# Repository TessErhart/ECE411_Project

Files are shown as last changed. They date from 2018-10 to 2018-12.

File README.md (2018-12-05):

# ECE411 Project 2018
Group 2
Team members: Tess Erhart, Jennifer Lara, Brandon Barber, and Martin Rodriguez

# Word Clock

Concept: Rather than displaying the time like a traditional clock, this clock uses LEDs to light words on a panel, “spelling out” the time.

Inspiration:<br/>
<https://www.amazon.com/LED-Word-Clock-Displays-Powered/dp/B00JPNWR3G><br/>
<https://www.instructables.com/id/Wordclock/>

/datasheets: Contains all relevant datasheets<br/>
/docs: Contains all relevant documents, schematics, layouts, testing plans, etc.<br/>
/rtc_ds3231: Contains all code<br/>
/schematics: Contains all schematics and layouts<br/>

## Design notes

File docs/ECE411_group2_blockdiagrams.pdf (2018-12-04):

Group 2:
Teresa Erhart
Jennifer Lara
Charles Barber
Martin Rodriguez

ECE 411

29 November 2018

Level 0 block diagram for Word Clock module

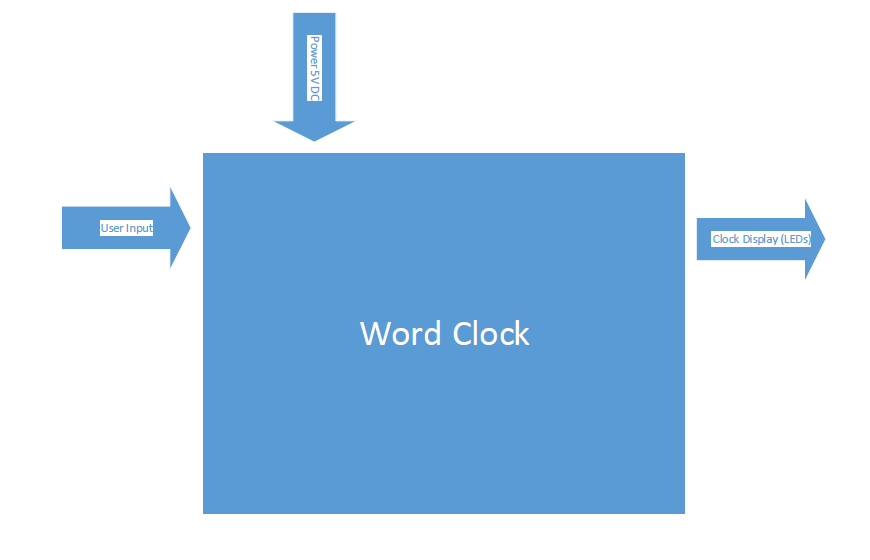
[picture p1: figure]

Module | Word Clock
Inputs | Power: 5V DC User control
Outputs | Display: LEDs
Functionality | User sets clock via pushbutton input. Word clock outputs LED voltages, which have been demultiplexed. LEDs are displayed through laser-cut acrylic so that words are shown representing the time.

Level 1 block diagram for Word Clock module

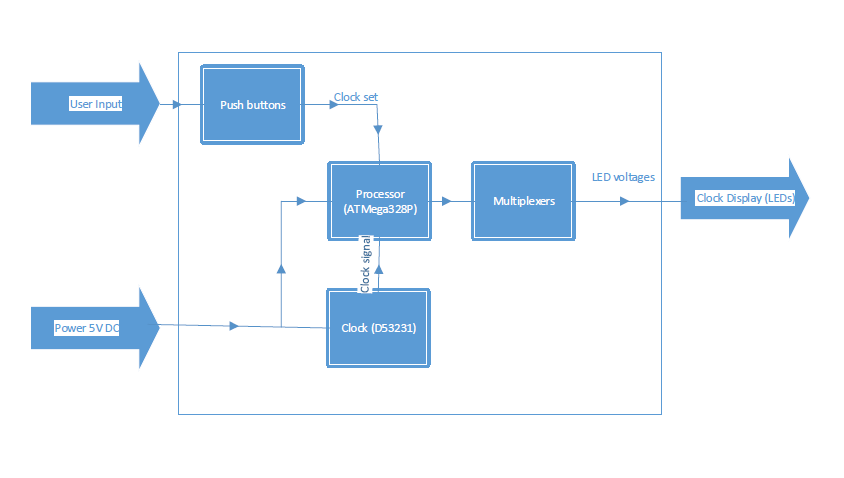
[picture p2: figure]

Module | Word Clock
Inputs | Power: 5V DC User control: two push buttons, A and B
Outputs | Display: LEDs (demultiplexed LED voltages)
Functionality | Push buttons are used to set clock. Clock provides signal to processor. Processor produces multiplexed signal, which must be demultiplexed to drive the LED display. Each LED represents a word, which is displayed through laser-cut acrylic to produce the word visually.

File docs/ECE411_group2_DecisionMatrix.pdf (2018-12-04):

Teresa Erhart
Charles Barber
Martin Rodriguez
Jennifer Lara

### ECE-411 Decision Matrix, Group Two

Introduction:

For our ECE-411 project we used a variety of decisions matrices to narrow down and conclude certain components of our project. These decisions lead to successful project development techniques within our group. Below is a list of our four entries:

Decision Matrix One: Deciding on our Practicum Project Based on Difficulty:

For the first decision matrix we implemented, it involved choosing our practicum project. We arranged the projects into a table and broke them down based off how difficult we though they would be on a scale of one to five. One being the easiest and five being the hardest. Below is a look at what this table was composed of:

Project Ideas: | Difficulty (1 to 5):
Guitar Modulator | 5
Collision Sensor | 4
Multidirectional LED Audio Sensor | 4
Word Clock | 2

Now these values that we listed were just a combination of us as a group talking through the time that each one would take to build, the construction, and overall difficulty. These values were also the average number that all of us individually came up with based off our thoughts of the project.

Decision Matrix Two: Layout and Designs Further Breakdown

Deciding what we wanted the board to look like, what components, the sizing, etc. all were up for consideration. Budget is also a big factor, so we needed to make a matrix of what we wanted vs. was this realistic for the time and money we have, also the factor of is this consumer friendly.

Each category graded on a 1 to 10 scale: | Guitar Modulator | Collision Sensor | Multidirectional LED Audio Sensor | Word Clock
Cost: | 7 | 5 | 8 | 4
Time: | 9 | 6 | 8 | 4
Size: | 4 | 3 | 7 | 4
Consumer Consumption: (in this case lower is better) | 3 | 5 | 7 | 2
Total: | 23 | 19 | 30 | 14

As we can see from the matrix above, the lower value is better and the project we would decide on.

Teresa Erhart
Charles Barber
Martin Rodriguez
Jennifer Lara
Decision Matrix Three: Word Clock, Breaking up the work

The next important factor that we though of was creating a decision matrix of our strengths. Group organization is key when creating a project. So, we built a matrix of who has strengths in certain areas and can contribute the most in that area or take lead.

Group Member: | Soldering: | Eagle: PCB Layout | Eagle: Schematic | Coding: | GitHub: | Documentation:
Teresa | x | x | x | | | x
Martin | x | | | | x | x
Jennifer | x | | x | x | | x
Charles | x | x | | | | x

Again, these areas don’t reflect what a person solely focused on, just more so what their main strengths are and if they can take lead and teach others in these categories.

Decision Matrix Four: Concept Tables

Below is a concept table we used when deciding what we wanted the board to be composed of:

Display | Power | Size | Enclosure Style
LED Only Display | AC Power | Credit Card Size | Wood
Backlit “Plastic Display” | 9V Battery | Small Enclosed Box | Plastic
LCD Screen | USB | Small Picture Frame | Metal
Laser Etched, for Backlit display | | Phone Sized | 3D-Print

This helped us on a solid design style for the Word Clock.

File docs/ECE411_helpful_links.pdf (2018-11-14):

Overall guide to building a word clock: https://www.instructables.com/id/Wordclock/

Using Inkscape to design a laser cut a stencil: https://www.sculpteo.com/en/tutorial/prepare-your-model-laser-cutting-inkscape/

Using ATMEGA328 with Arduino: https://www.instructables.com/id/2-Arduino-the-ATMEGA328-As-a-Stand-alone-Easy-Chea/

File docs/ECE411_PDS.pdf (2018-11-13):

Names: Teresa Erhart,
Jennifer Lara,
Charles Barber,
Martin Rodriguez
Assignment: Product
Design Specification
Class: ECE 411

## Executive Summary / Concept of Operations

The device reads the current time from a clock chip, then displays the time on a clock by backlighting the appropriate words that spell out the time. The clock tells you the time using an expected formula. For example if the time is 8:15, only the phrases It is, quarter, past, eight, and o’clock will be lit. The device is meant to be a decorative wall clock.

## Brief Market Analysis

- Who are the intended customers?
People who like techie toys without the skill sets or just don’t have the time to build this themselves, people with dyscalculia.
- What is the competition? Why is your product different?
There are not that many of these out on the market. Most sell between $400-$2200. It would be fairly straightforward to design a clock that can sell at a much lower price point, while still maintaining a very high profit margin per unit. The clock tells you the time in actual words, which may be a good alternative to a digital clock for individuals with dyscalculia (unverified). In addition, I have been unable to find many clocks for sale that have any additional features, which gives us room to expand future versions. They could include alarms, changing light colors, wifi communication to also display weather, etc without adding too much complexity.
- What price will do you think you can sell this for, and why?
For this base first version model, a cost of ~ $150 -$200 will keep us at less than half of the vast majority of the models currently available.

## Requirements

### The Model Must

- Have LEDs bright enough to see in a well lit room
- Be fully enclosed to look like a finished product
- Be powered by something the customer can easily handle (ie easily changeable batteries or a power cord)
- Be able to be manufactured with an absolute minimum of hand assembly
- Operate reliably in a range of normal room temperatures (~20-25 °C)

Names: Teresa Erhart,
Jennifer Lara,
Charles Barber,
Martin Rodriguez
Assignment: Product
Design Specification
Class: ECE 411

### The Model Should

- Use easily attainable off the shelf components
- Be attractive

### The Model May

- Have consumer changeable LEDs to extend the lifetime of the product
- Have the ability for the user to control LED brightness
- Have an alarm

## System Architecture

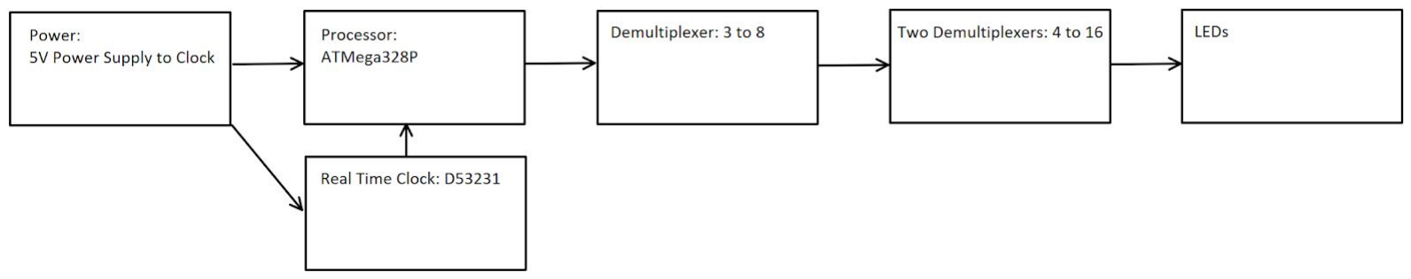
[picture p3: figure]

## Design Specification

Sensor: Push buttons for user to set the time, clock chip (DS3231) Processor: ATMega328
Actuator: Multiplexer/demultiplexer to LED display
Power: 5v vcc from 9v battery
Mechanical design: 3D-printed or laser-cut isolator for LED housing, laser-cut faceplate with opaque vinyl/plastic sheet to diffuse LED light. Thinking about various materials for clock housing (wood, copper, etc). No moving parts.
Firmware: Arduino bootloader, clock program written in C Development environment: Arduino IDE/Vim

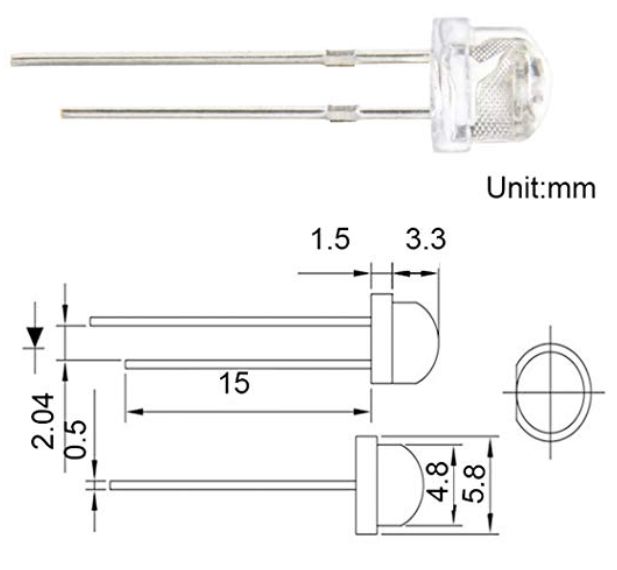
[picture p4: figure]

Collaboration will be done through Github.

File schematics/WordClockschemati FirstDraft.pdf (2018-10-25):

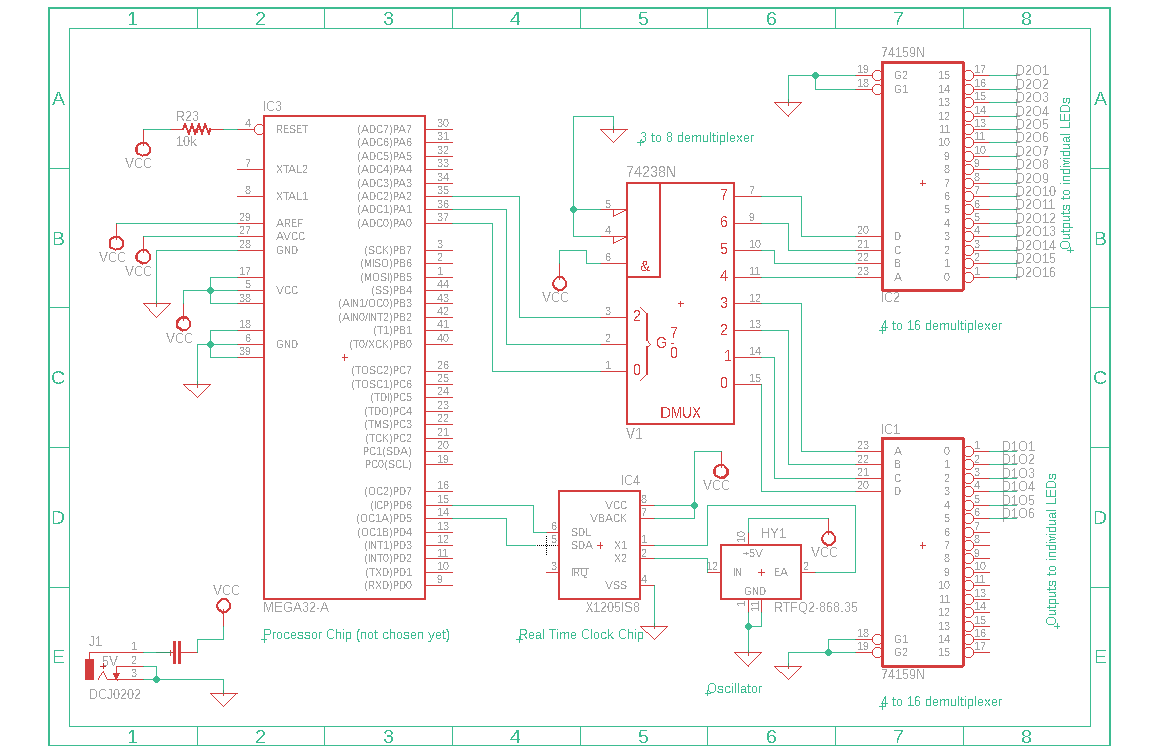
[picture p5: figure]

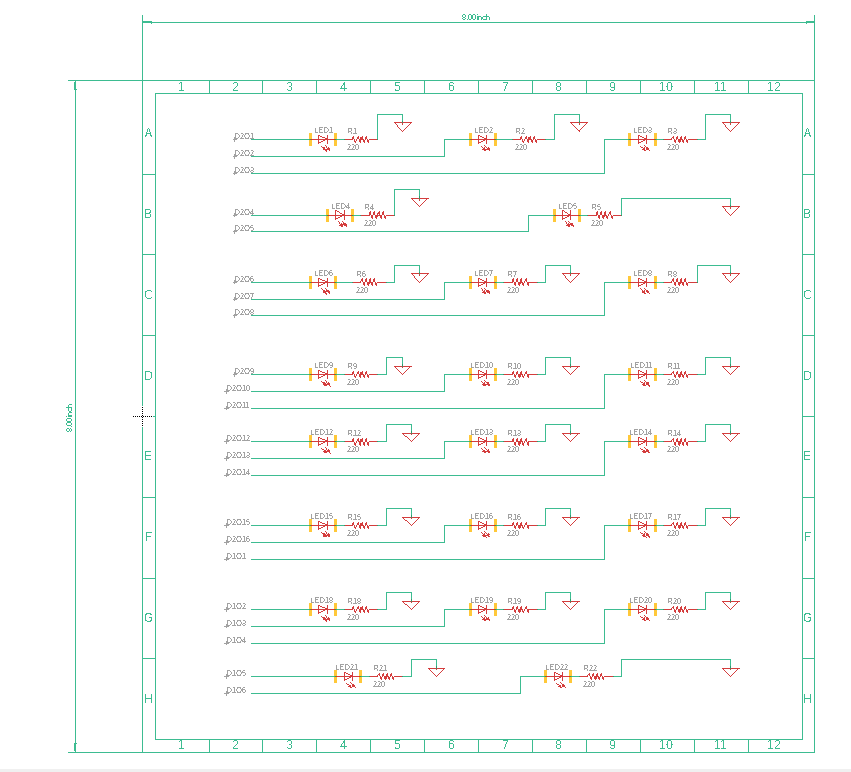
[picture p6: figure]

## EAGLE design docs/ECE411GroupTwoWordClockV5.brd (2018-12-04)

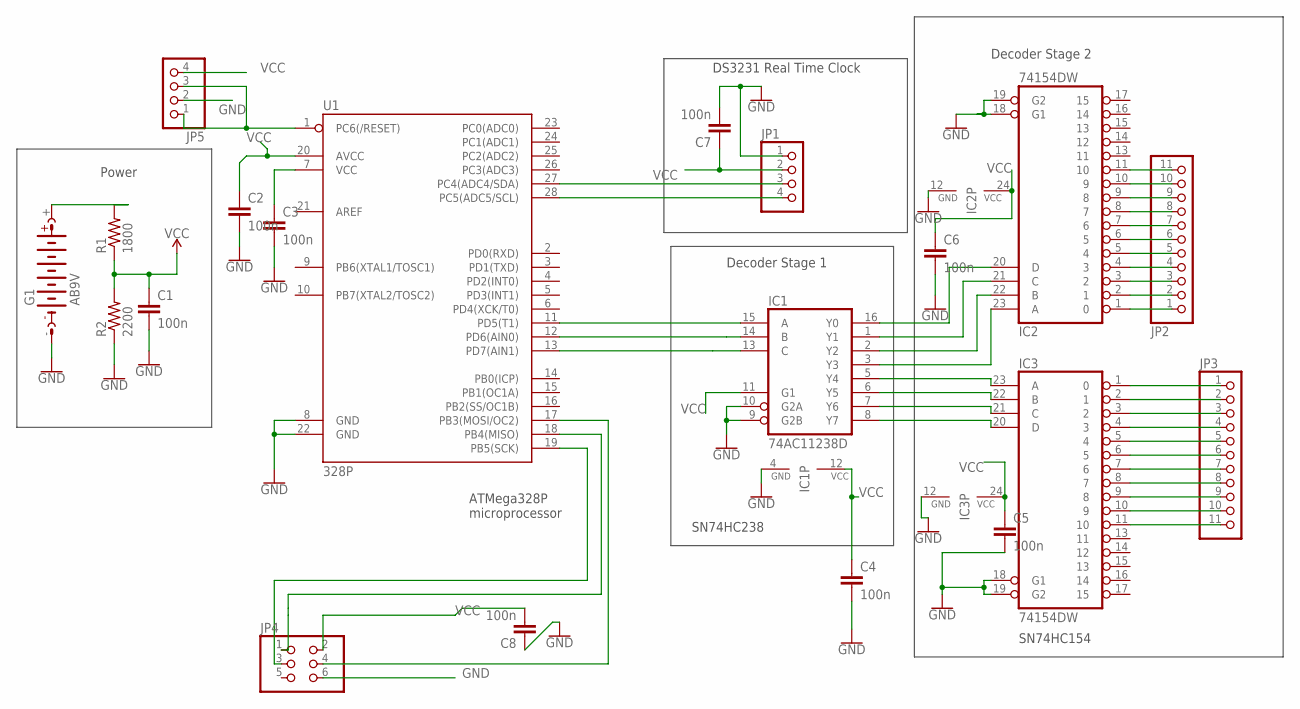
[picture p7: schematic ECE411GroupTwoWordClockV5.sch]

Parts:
C1, C2, C3, C4, C5, C6, C7, C8: 100n; C025-025X050
G1: AB9V
IC1: 74AC11238D; SO16
IC2, IC3: 74154DW; SO24W
JP1, JP5: PINHD-1X4; 1X04
JP2, JP3: PINHD-1X11; 1X11
JP4: PINHD-2X3; 2X03
R1: 1800; 0204V
R2: 2200; 0204V
U1: 328P; DIP28

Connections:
GND: C1.2, C2.2, C3.2, C4.2, C5.2, C6.2, C7.2, C8.1, G1.-, IC1.4 (GND), IC1.9 (G2B), IC1.10 (G2A), IC2.12 (GND), IC2.18 (G1), IC2.19 (G2), IC3.12 (GND), IC3.18 (G1), IC3.19 (G2), JP1.1, JP4.6, JP5.2, R2.1, U1.8 (GND), U1.22 (GND)
unnamed: G1.+, R1.2
unnamed: JP1.4, U1.28 (PC5(ADC5/SCL))
unnamed: JP1.3, U1.27 (PC4(ADC4/SDA))
unnamed: IC1.15 (A), U1.11 (PD5(T1))
unnamed: C3.1, U1.7 (VCC)
unnamed: IC1.13 (C), U1.13 (PD7(AIN1))
unnamed: IC1.3 (Y3), IC2.23 (A)
unnamed: IC1.2 (Y2), IC2.22 (B)
unnamed: IC1.1 (Y1), IC2.21 (C)
unnamed: IC1.16 (Y0), IC2.20 (D)
unnamed: IC2.1 (0), JP2.1
unnamed: IC2.2 (1), JP2.2
unnamed: IC2.3 (2), JP2.3
unnamed: IC2.4 (3), JP2.4
unnamed: IC2.5 (4), JP2.5
unnamed: IC1.14 (B), U1.12 (PD6(AIN0))
unnamed: IC2.6 (5), JP2.6
unnamed: IC2.7 (6), JP2.7
unnamed: IC2.8 (7), JP2.8
unnamed: IC2.9 (8), JP2.9
unnamed: IC2.10 (9), JP2.10
unnamed: IC1.5 (Y4), IC3.23 (A)
unnamed: IC1.6 (Y5), IC3.22 (B)
unnamed: IC1.7 (Y6), IC3.21 (C)
unnamed: IC3.1 (0), JP3.1
unnamed: IC1.8 (Y7), IC3.20 (D)
unnamed: IC3.2 (1), JP3.2
unnamed: IC3.3 (2), JP3.3
unnamed: IC3.4 (3), JP3.4
unnamed: IC3.5 (4), JP3.5
unnamed: IC3.6 (5), JP3.6
unnamed: IC3.7 (6), JP3.7
unnamed: IC3.8 (7), JP3.8
unnamed: IC3.9 (8), JP3.9
unnamed: IC3.10 (9), JP3.10
unnamed: IC3.11 (10), JP3.11
unnamed: IC2.11 (10), JP2.11
unnamed: JP4.1, U1.18 (PB4(MISO))
unnamed: JP4.3, U1.19 (PB5(SCK))
unnamed: JP4.4, U1.17 (PB3(MOSI/OC2))
unnamed: JP5.1, JP5.3, U1.1 (PC6(/RESET))
VCC: C1.1, C2.1, C4.1, C5.1, C6.1, C7.1, C8.2, IC1.11 (G1), IC1.12 (VCC), IC2.24 (VCC), IC3.24 (VCC), JP1.2, JP4.2, JP5.4, R1.1, R2.2, U1.20 (AVCC)

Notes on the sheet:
Power
ATMega328P microprocessor
DS3231 Real Time Clock
Decoder Stage 1
Decoder Stage 2
SN74HC154
SN74HC238

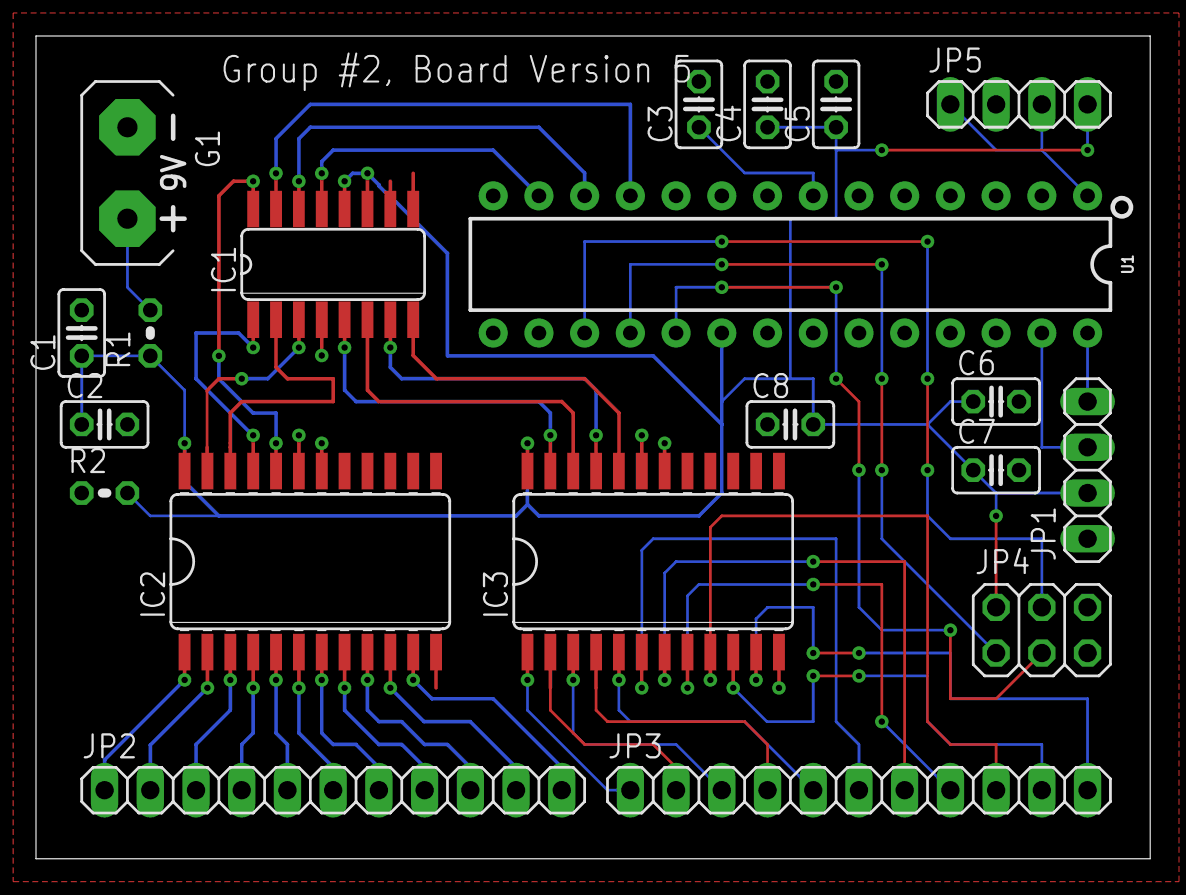
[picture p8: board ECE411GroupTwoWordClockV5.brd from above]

Board: 2 copper layers, 61.9 x 45.7 mm, 20 parts (0 on the bottom side), 43 nets.

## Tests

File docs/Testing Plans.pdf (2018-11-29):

Names: Teresa Erhart,
Jennifer Lara,
Charles Barber,
Martin Rodriguez
Assignment: Test Plans
Class: ECE 411
Test Plan for Initial Power Up of Practicum Project
Specific System being Tested: ATMega328
Required Materials: LEDs, Multiplexer/demultiplexer, 9v Battery, clock chip(DS3231), push buttons, LED screen

Test Case: Battery Test

Module | Make sure battery has correct Voltage
Inputs | Voltage Testing Device
Outputs | 9V
Functionality | Functional Testing
Objective | Making sure we have a good battery

Test Case: Chip Testing

Module | Verify Chip Connections
Inputs | High Input for each configuration
Outputs | Verify expected output
Functionality | Functional Testing
Objective | In order to make sure the connections were soldered well

Test Case: Testing Each LED

Module | LED Test
Inputs | Send high signal to LED
Outputs | LED lights up
Functionality | Functional Testing
Objective | Making sure that each LED works

Test Case: Power Test

Martin Rodriguez
Assignment: Test Plans
Class: ECE 411
Module | Verify System has enough Power
Inputs | 9v Battery
Outputs | Voltage on decoder pins
Functionality | Functional Test
Objective | The system needs enough power to provide for the rest. One way of noticing this is checking the decoder pins have enough voltage.

Test Case: Installation Test

Module | Verify System has software needed to run clock program
Inputs | Arduino to burn bootloader into ATMega328
Outputs | No error messages when uploading a simple program
Functionality | Functional Test
Objective | The system needs to be able to run a program without any software issues.

Test Case: Integration Test

Module | Verify integration of ATMega328’s software with the Multiplexer/demultiplexer & LEDs
Inputs | Power to Processor and Clock
Outputs | LEDs
Functionality | Functional Testing
Objective | Make sure that the clock impacts the output of the processor

Test Case: Use Test

Module | Press button to Set Clock

Martin Rodriguez
Assignment: Test Plans
Class: ECE 411
Inputs | Button Press
Outputs | Correct Clock time on LED screen
Functionality | Acceptance Testing
Objective | Make sure that the clock is going at the right time

Test Case: Cycle time fast

Module | Time Go Fast
Inputs | Timing changes to the ATMega328
Outputs | Outputs should cycle through relatively quickly to avoid waiting hours
Functionality | Functional Testing
Objective | Verify that the inputs pass through the system and give the correct timing output

Test Case: Error Test

Module | No button press to change time in system
Inputs | N/A
Outputs | Expected wrong time
Functionality | Error testing
Objective | Stress Testing

Martin Rodriguez
Assignment: Test Plans
Class: ECE 411

Test Plan 2
On another system, test involving one performance test from requirements

The performance requirement being tested on another system is
- Have LEDs bright enough to see in a well lit room
Black Box Testing: Testing a module or system only with knowledge of its external specification (e.g. inputs, outputs, functionality) and using only inputs and outputs.

This system test is checking that the button setting the clock input goes into the system and outputs the desired LED outputs.

Module | LED
Inputs | Coding will be substituted for clock inputs at a high cycle rate
Outputs | LEDs
Functionality | LED output testing
Objective | Cycle the LEDs in direct sun (if possible) and indoor lighting to determine if they are bright enough to be visible
Module | Entire System
Inputs | Coding will be substituted for clock inputs at a high cycle rate
Outputs | LEDs
Functionality | System Test
Objective | To test the whole system at an increased rate

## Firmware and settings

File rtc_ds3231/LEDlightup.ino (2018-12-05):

/*
demo test
Turn on the serial monitor after loading this to check if things are
working as they should.
411 Code for Word Clock. Need to still add the outputs that ATMega328 would send
*/

#include "ds3231.h"
#include <Wire.h>

//DS3231 Clock;
bool Century=false;
bool h12;
bool PM;
byte ADay, AHour, AMinute, ASecond, ABits;
bool ADy, A12h, Apm;
//Pins 5,6,7 are arduino pins which correlate to pins 11, 12, 13
//MUX 1
int muxPin1 = 2; //pin 4 on ATMega328 (A for 72ac11238d)
int muxPin2 = 3; //pin 5 on ATMega328 (B)
int muxPin3 = 4; //pin 6 on ATMega328 (C)
//MUX 2
int muxPin4 = 5; //pin 11 on ATMega328 (A for 72ac11238d)
int muxPin5 = 6; //pin 12 on ATMega328 (B)
int muxPin6 = 7; //pin 13 on ATMega328 (C)
//MUX 3
int muxPin7 = 8; //pin 14 on ATMega328 (A for 72ac11238d)
int muxPin8 = 9; //pin 15 on ATMega328 (B)
int muxPin9 = 10;//pin 16 on ATMega328 (C)


int hotmin;
int hothr;
uint8_t time[8];

//functions
void displaytime(void);
void checknum(int num);
void printbintime(int ihour, int iminute);
void turnonLED22(void);
void clearLEDs(void);
void demotest(void);
void clearLEDs(void)
{
      digitalWrite(muxPin1, LOW); // off
      digitalWrite(muxPin2, LOW); // off
      digitalWrite(muxPin3, LOW); // 0ff
      digitalWrite(muxPin4, LOW); // off
      digitalWrite(muxPin5, LOW); // off
      digitalWrite(muxPin6, LOW); // 0ff
      digitalWrite(muxPin7, HIGH); // off
      digitalWrite(muxPin8, HIGH); // off
      digitalWrite(muxPin9, HIGH); // 0ff
      delay(1000);
}
void checknum(int num)
{
    if(num > 12)
    {
        num = num - 12;
    }
    if(num == 1){
      Serial.print("Light up LED 12(1) ");
      //Send msg to LED12 (100)
      digitalWrite(muxPin4, LOW); // on
      digitalWrite(muxPin5, LOW); // on
      digitalWrite(muxPin6, HIGH); // off
    }
    else if(num == 2){
      Serial.print("Light up LED 10(2) ");
      //Send msg to LED10 (010)
      digitalWrite(muxPin4, LOW); // off
      digitalWrite(muxPin5, HIGH); // on
      digitalWrite(muxPin6, LOW); // 
    }
    else if(num == 3){
      Serial.print("Light up LED 11(3) ");
      //Send msg to LED11 (011)
      digitalWrite(muxPin4, HIGH); // on
      digitalWrite(muxPin5, HIGH); // on
      digitalWrite(muxPin6, LOW); // oFF
    }
    else if(num == 4){
      Serial.print("Light up LED 13(4) ");
      //Send msg to LED13 (101)
      digitalWrite(muxPin4, HIGH); // on
      digitalWrite(muxPin5, LOW); // off
      digitalWrite(muxPin6, HIGH); // on
    }
    else if(num == 5){
      Serial.print("Light up LED 14(5) ");
      //Send msg to LED14 (110)
      digitalWrite(muxPin4, LOW); // on
      digitalWrite(muxPin5, HIGH); // off
      digitalWrite(muxPin6, HIGH); // on
    }
    else if(num == 6){
      Serial.print("Light up LED 15(6) ");
      //Send msg to LED15 (111)
      digitalWrite(muxPin4, HIGH); // on
      digitalWrite(muxPin5, HIGH); // on
      digitalWrite(muxPin6, HIGH); // on
    }
    else if(num == 7){
      Serial.print("Light up LED 16(7) ");
      //Send msg to LED16 (000)
      digitalWrite(muxPin7, LOW); // off
      digitalWrite(muxPin8, LOW); // off
      digitalWrite(muxPin9, LOW); // off
    }
    else if(num == 8){
      Serial.print("Light up LED 17(8) ");
      //Send msg to LED17 (001)
      digitalWrite(muxPin7, HIGH); // onn
      digitalWrite(muxPin8, LOW); // off
      digitalWrite(muxPin9, LOW); // 0ff
    }
    else if(num == 9){
      Serial.print("Light up LED 18(9) ");
      //Send msg to LED18 (010)
      digitalWrite(muxPin7, LOW); // 
      digitalWrite(muxPin8, HIGH); // 
      digitalWrite(muxPin9, LOW); //
    }
    else if(num == 10){
      Serial.print("Light up LED 19(10) ");
      //Send msg to LED19 (011)
      digitalWrite(muxPin7, HIGH); // 
      digitalWrite(muxPin8, HIGH); // 
      digitalWrite(muxPin9, LOW); //
    }
    else if(num == 11){
      Serial.print("Light up LED 20(11) ");
      //Send msg to LED20 (100)
      digitalWrite(muxPin7, LOW); // 
      digitalWrite(muxPin8, LOW); // 
      digitalWrite(muxPin9, HIGH); //
    }
    else if(num == 12){
      Serial.print("Light up LED 21(12) ");
      //Send msg to LED21 (101)
      digitalWrite(muxPin7, HIGH); // 
      digitalWrite(muxPin8, LOW); // 
      digitalWrite(muxPin9, HIGH); //
    }
    delay(1000);
    Serial.print("Light up LED 22(o'clock)~ ");
    turnonLED22();
    clearLEDs();  
    delay(1000); //delay a second
}
void turnonLED22(void)
{
        //Send msg to LED22 (110)
        digitalWrite(muxPin7, LOW); // 
        digitalWrite(muxPin8, HIGH); // 
        digitalWrite(muxPin9, HIGH); //  
        delay(1000);
}
void printbintime(int ihour, int iminute)
{
 /* char nums[][10] = { "zero", "one", "two", "three", "four",
                         "five", "six", "seven", "eight", "nine",
                         "ten", "eleven", "twelve", "thirteen",
                         "fourteen", "fifteen", "sixteen", "seventeen",
                         "eighteen", "nineteen", "twenty", "thirty", "forty",
                         "fifty", "O'Clock" ,"half", "quarter", "past", "to"
                      };*/
  if( ihour == 0 ){
    ihour = 12;}
  displaytime();
  if(iminute < 15){
      if(iminute < 15){
        //printf("%s o'clock\n", nums[ihour]);
        checknum(ihour);
//        Serial.print("Light up LED 22(o'clock)~ ");
//        turnonLED22();
      }
      else if(iminute == 0){
        //printf("%s o'clock\n", nums[ihour]);
//        Serial.print("Light up LED 22(o'clock) ");
//        turnonLED22();
        checknum(ihour);
      }
    }
/*  else if(iminute < 10)
  {
        //printf("%s minutes past %s o'clock\n", nums[iminute], nums[ihour]);
        checknum(iminute);
        Serial.print("Light up LEDs 7 & 9(minutes past)");
        checknum(ihour);
        Serial.print("Light up LED 22(o'clock)");
  }*/
  if((iminute >= 15) && (iminute < 30)){
        //printf("quarter past %s \n", nums[ihour]);
        Serial.print("Light up LED 4 & 9(quarter past) ");
        //Send msg to LED4 (011)
        digitalWrite(muxPin1, HIGH); // on
        digitalWrite(muxPin2, HIGH); // on
        digitalWrite(muxPin3, LOW); // off
        delay(1000);
        //Send msg to LED9 (001)
        digitalWrite(muxPin4, HIGH); // on
        digitalWrite(muxPin5, LOW); // off
        digitalWrite(muxPin6, LOW); // off
        delay(1000);
        checknum(ihour);
//        Serial.print("Light up LED 22(o'clock)~ ");
//        turnonLED22();

  }
  if((iminute >= 30) ){
       if(iminute < 45){
        //printf("half past %s\n", nums[ihour]);
        Serial.print("Light up LED 2 & 9(half past)~ ");
        //Send msg to LED2 (001)
        digitalWrite(muxPin1, HIGH); // on
        digitalWrite(muxPin2, LOW); // on
        digitalWrite(muxPin3, LOW); // off
        delay(1000);
        //Send msg to LED9 (001)
        digitalWrite(muxPin4, HIGH); // on
        digitalWrite(muxPin5, LOW); // off
        digitalWrite(muxPin6, LOW); // off
        delay(1000);
        checknum(ihour);
 //       Serial.print("Light up LED 22(o'clock)~ ");
//        turnonLED22();

       }
       else if(iminute == 30){
        //printf("half past %s\n", nums[ihour]);
        Serial.print("Light up LED 2 & 9(half past) ");
        //Send msg to LED2 (001)
        digitalWrite(muxPin1, HIGH); // on
        digitalWrite(muxPin2, LOW); // on
        digitalWrite(muxPin3, LOW); // off
        delay(1000);
        //Send msg to LED9 (001)
        digitalWrite(muxPin4, HIGH); // on
        digitalWrite(muxPin5, LOW); // off
        digitalWrite(muxPin6, LOW); // off
        delay(1000);
        checknum(ihour);
//        Serial.print("Light up LED 22(o'clock)~ ");
//        turnonLED22();
        }
  }
 
 if(iminute >= 45){
     if (iminute < 60){
        //printf("quarter to %s\n", nums[(ihour % 12) + 1]);
        Serial.print("Light up LED 4 & 8(quarter to)~  ");
        //Send msg to LED4 (011)
        digitalWrite(muxPin1, HIGH); // on
        digitalWrite(muxPin2, HIGH); // on
        digitalWrite(muxPin3, LOW); // off
        delay(1000);
        //Send msg to LED8 (111)
        digitalWrite(muxPin1, HIGH); // on
        digitalWrite(muxPin2, HIGH); // on
        digitalWrite(muxPin3, HIGH); // onn
        delay(1000);
        checknum((ihour % 12) + 1);
//        Serial.print("Light up LED 22(o'clock)~ ");
//        turnonLED22();

      }
      else if(iminute == 45){
        //printf("quarter to %s\n", nums[(ihour % 12) + 1]);
        Serial.print("Light up LED 4 & 8(quarter to) ");
        //Send msg to LED4 (011)
        digitalWrite(muxPin1, HIGH); // on
        digitalWrite(muxPin2, HIGH); // on
        digitalWrite(muxPin3, LOW); // off
        delay(1000);
        //Send msg to LED8 (111)
        digitalWrite(muxPin1, HIGH); // on
        digitalWrite(muxPin2, HIGH); // on
        digitalWrite(muxPin3, HIGH); // onn
        delay(1000);
        checknum((ihour % 12) + 1);


      }
 }
 // clearLEDs();

  Serial.print("\n-------------");
}

void displaytime(void){
  // Now, turn on the "It is" leds
  //Serial.print("It is \n");
  Serial.print("Light up LED 1(It is) "); 
  //Send msg to LED1 (000)
//  digitalWrite(muxPin1, LOW); // off
//  digitalWrite(muxPin2, LOW); // off
//  digitalWrite(muxPin3, LOW); // off
  delay(5000);
}
void setup() {
  // Start the I2C interface
  Wire.begin();
  // initialize digital pins as an output.
  
  pinMode(muxPin1, OUTPUT);
  pinMode(muxPin2, OUTPUT);
  pinMode(muxPin3, OUTPUT);
  pinMode(muxPin4, OUTPUT);
  pinMode(muxPin5, OUTPUT);
  pinMode(muxPin6, OUTPUT);
  pinMode(muxPin7, OUTPUT);
  pinMode(muxPin8, OUTPUT);
  pinMode(muxPin9, OUTPUT);


  // Start the serial interface
  Serial.begin(9600);
}
void demotest(void)
{
    //Variables
    int h = 0;
    int m = 0;
    int i = 0;
    int j = 0;
     // use for demo test later?
     
     for(i=0;i<12;i++)
     {
         for(j=0;j<4;j++)
         {
             printbintime(h, m); 
            m = m + 15;
            delay(250);
            Serial.print("Time change\n");
         }
         h++;
         m = 0;
     }
}
void loop() {
  // send what's going on to the serial monitor.
  //the output should be whatever the decoder expects.( but i'll add stuff to let me light up LEDS
  char buff[128];
//  DS3231_get_a1(&buff[0], 59);
//  Serial.println(buff);
  struct ts t;
  int hotmin = t.min;
  int hothr =  t.hour; 
  Serial.print(hothr);
  Serial.print(":");
  Serial.print(hotmin);
  Serial.print("   ");
 // printbintime(hothr,hotmin);
  demotest();
  DS3231_get(&t);

        snprintf(buff, 128, "%d.%02d.%02d %02d:%02d:%02d", t.year,
            t.mon, t.mday, t.hour, t.min, t.sec);

  Serial.print('\n');
  Serial.print('\n');
  delay(1000);
}

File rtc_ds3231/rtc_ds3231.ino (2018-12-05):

#include <Wire.h>
#include "ds3231.h"

#define BUFF_MAX 128

uint8_t time[8];
char recv[BUFF_MAX];
unsigned int recv_size = 0;
unsigned long prev, interval = 5000;

void parse_cmd(char *cmd, int cmdsize);

void setup()
{
    Serial.begin(9600);
    Wire.begin();
    DS3231_init(DS3231_CONTROL_INTCN);
    memset(recv, 0, BUFF_MAX);
    Serial.println("GET time");

  //  Serial.println("Setting time");
  //Uncomment out the parse_cmd to set the time in clock
  //comment it back again in order to use LEDlightup
    //parse_cmd("T000017702122018", 16);
    // TssmmhhWDDMMYYYY aka set time
}

void loop()
{
    char in;
    char buff[BUFF_MAX];
    unsigned long now = millis();
    struct ts t;

    // show time once in a while
    if ((now - prev > interval) && (Serial.available() <= 0)) {
        DS3231_get(&t);

        // there is a compile time option in the library to include unixtime support
#ifdef CONFIG_UNIXTIME
#ifdef __AVR__
        snprintf(buff, BUFF_MAX, "%d.%02d.%02d %02d:%02d:%02d %ld", t.year,
#error AVR
#else
        snprintf(buff, BUFF_MAX, "%d.%02d.%02d %02d:%02d:%02d %d", t.year,
#endif
             t.mon, t.mday, t.hour, t.min, t.sec, t.unixtime);
#else
        snprintf(buff, BUFF_MAX, "%d.%02d.%02d %02d:%02d:%02d", t.year,
             t.mon, t.mday, t.hour, t.min, t.sec);
#endif

        Serial.println(buff);
        prev = now;
    }

    if (Serial.available() > 0) {
        in = Serial.read();

        if ((in == 10 || in == 13) && (recv_size > 0)) {
            parse_cmd(recv, recv_size);
            recv_size = 0;
            recv[0] = 0;
        } else if (in < 48 || in > 122) {;       // ignore ~[0-9A-Za-z]
        } else if (recv_size > BUFF_MAX - 2) {   // drop lines that are too long
            // drop
            recv_size = 0;
            recv[0] = 0;
        } else if (recv_size < BUFF_MAX - 2) {
            recv[recv_size] = in;
            recv[recv_size + 1] = 0;
            recv_size += 1;
        }

    }
}

void parse_cmd(char *cmd, int cmdsize)
{
    uint8_t i;
    uint8_t reg_val;
    char buff[BUFF_MAX];
    struct ts t;

    //snprintf(buff, BUFF_MAX, "cmd was '%s' %d\n", cmd, cmdsize);
    //Serial.print(buff);

    // TssmmhhWDDMMYYYY aka set time
    if (cmd[0] == 84 && cmdsize == 16) {
        //T355720619112011
        t.sec = inp2toi(cmd, 1);
        t.min = inp2toi(cmd, 3);
        t.hour = inp2toi(cmd, 5);
        t.wday = cmd[7] - 48;
        t.mday = inp2toi(cmd, 8);
        t.mon = inp2toi(cmd, 10);
        t.year = inp2toi(cmd, 12) * 100 + inp2toi(cmd, 14);
        DS3231_set(t);
        Serial.println("OK");
    } else if (cmd[0] == 49 && cmdsize == 1) {  // "1" get alarm 1
        DS3231_get_a1(&buff[0], 59);
        Serial.println(buff);
    } else if (cmd[0] == 50 && cmdsize == 1) {  // "2" get alarm 1
        DS3231_get_a2(&buff[0], 59);
        Serial.println(buff);
    } else if (cmd[0] == 51 && cmdsize == 1) {  // "3" get aging register
        Serial.print("aging reg is ");
        Serial.println(DS3231_get_aging(), DEC);
    } else if (cmd[0] == 65 && cmdsize == 9) {  // "A" set alarm 1
        DS3231_set_creg(DS3231_CONTROL_INTCN | DS3231_CONTROL_A1IE);
        //ASSMMHHDD
        for (i = 0; i < 4; i++) {
            time[i] = (cmd[2 * i + 1] - 48) * 10 + cmd[2 * i + 2] - 48; // ss, mm, hh, dd
        }
        uint8_t flags[5] = { 0, 0, 0, 0, 0 };
        DS3231_set_a1(time[0], time[1], time[2], time[3], flags);
        DS3231_get_a1(&buff[0], 59);
        Serial.println(buff);
    } else if (cmd[0] == 66 && cmdsize == 7) {  // "B" Set Alarm 2
        DS3231_set_creg(DS3231_CONTROL_INTCN | DS3231_CONTROL_A2IE);
        //BMMHHDD
        for (i = 0; i < 4; i++) {
            time[i] = (cmd[2 * i + 1] - 48) * 10 + cmd[2 * i + 2] - 48; // mm, hh, dd
        }
        uint8_t flags[5] = { 0, 0, 0, 0 };
        DS3231_set_a2(time[0], time[1], time[2], flags);
        DS3231_get_a2(&buff[0], 59);
        Serial.println(buff);
    } else if (cmd[0] == 67 && cmdsize == 1) {  // "C" - get temperature register
        Serial.print("temperature reg is ");
        Serial.println(DS3231_get_treg(), DEC);
    } else if (cmd[0] == 68 && cmdsize == 1) {  // "D" - reset status register alarm flags
        reg_val = DS3231_get_sreg();
        reg_val &= B11111100;
        DS3231_set_sreg(reg_val);
    } else if (cmd[0] == 70 && cmdsize == 1) {  // "F" - custom fct
        reg_val = DS3231_get_addr(0x5);
        Serial.print("orig ");
        Serial.print(reg_val,DEC);
        Serial.print("month is ");
        Serial.println(bcdtodec(reg_val & 0x1F),DEC);
    } else if (cmd[0] == 71 && cmdsize == 1) {  // "G" - set aging status register
        DS3231_set_aging(0);
    } else if (cmd[0] == 83 && cmdsize == 1) {  // "S" - get status register
        Serial.print("status reg is ");
        Serial.println(DS3231_get_sreg(), DEC);
    } else {
        Serial.print("unknown command prefix ");
        Serial.println(cmd[0]);
        Serial.println(cmd[0], DEC);
    }
}

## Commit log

2018-11-14 reorganized (or tried to)
    [411V2.sch]
2018-12-04 Add files to docs
    [ECE411GroupTwoWordClockV5.brd, ECE411GroupTwoWordClockV5.sch]

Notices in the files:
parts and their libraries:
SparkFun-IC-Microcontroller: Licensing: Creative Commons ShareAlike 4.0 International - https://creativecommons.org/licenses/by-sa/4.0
